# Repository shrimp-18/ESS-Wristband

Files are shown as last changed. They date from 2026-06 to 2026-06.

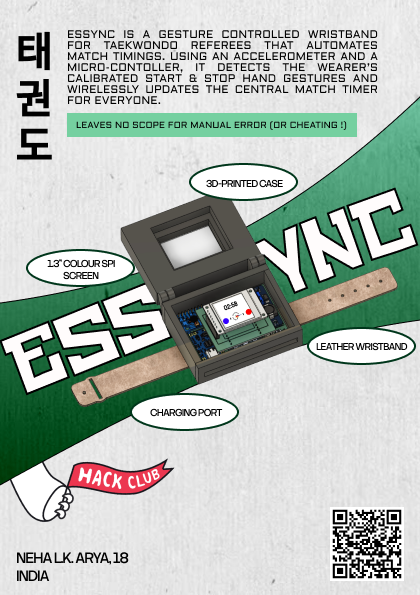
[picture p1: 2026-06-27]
Images/zine2.png

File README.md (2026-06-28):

# ESSync Wristband

A gesture-controlled referee wristband that automates match timing in Taekwondo. Using an accelerometer and microcontroller, it detects the referee’s calibrated start and stop gestures and wirelessly updates the central timer visible to everyone. This system removes manual jury control, ensuring accurate, fair, and transparent timekeeping.

---

## How it works

- Referee wants to stop the match.
- They make a swift hand movement used traditionally in Taekwondo.
- Players see this hand movement and stop.
- ESSync senses this swift hand movement and sends a signal to the central timer to stop.
- The central timer stops, and so do all the other sensors.
- Similar process repeats when the referee wants to restart the match.
zine3

<br>





---

## Why is ESSync Needed?

In Taekwondo matches, round timing is controlled by officials sitting at the jury table rather than by the referee overseeing the bout. This separation often leads to inconsistencies in the start and stop of the timer, whether due to human delay, miscommunication, or, in some cases, bias.
As a result, athletes can be unfairly advantaged or disadvantaged by inaccurate match durations, compromising the fairness and integrity of the competition.
There is a critical need for a referee-operated, automated, and transparent timing system that ensures real-time synchronisation and impartial timekeeping.

---

## So What's the solution?!

- A gesture-controlled wristband worn by referees to automate match timing.
- Uses an accelerometer and microcontroller to detect specific referee gestures.
- The downward "stop" motion of the hand instantly triggers the central arena timer wirelessly.
- Calibrated for each referee to prevent false detections and ensure precision.
- Removes jury dependency, ensuring fair, transparent, and real-time timekeeping.
- The timer part of Taekwondo matches isn’t automated yet and really needs a cheap and effective solution.
- Wristbands are easy to make and reliable.

---

## Components and their uses

| Component | Purpose |
|---|---|
| ESP32-C3 DevKitM-1 | Main MCU, the "brain" of the wristband |
| MPU6050 | Detects referee hand gestures |
| 1.3" 240×240 SPI Display | Displays timer and status |
| MT3608 | Boost converter |
| TP4056 | LiPo battery charger |

---


## Top PCB




---

## Bottom PCB





The project is made with two PCBs. The upper PCB holds the display, while the bottom PCB contains the MCU and all other components. This approach keeps the wristband compact without making it too wide. In future revisions, I plan to make it even smaller. The Case closes shut using the magnets present on the bottom part of the case and the lid of the case. The PCBs are snug in the case. The bottom PCB is also mounted to the bottom case by simply fitting the PCB's holes over the protruding cylindrical parts on the inner base of the case.

---

## Fusion Files

https://a360.co/4gCFWl9

---


## How to Build

## 1. Manufacture the PCBs
Fabricate both the **Top PCB** and **Bottom PCB** using the KiCad Files provided.

---

## 2. Prepare the Components

Purchase all required components listed in the **Bill of Materials (BOM)**.

---

## 3. Solder the Bottom PCB

Assemble the Bottom PCB first.
Solder All components and connectors to the bottom PCB according to the KiCad files given, and attach their respective components.

Refer to the schematic for the correct connector orientation and pin mapping.

---

## 4. Assemble the Top PCB

1. Solder the female headers for the ESP32 connector(on the bottom side).
2. Solder the male headers for the SPI Screen(on the top side).
3. Connect the SPI Screen.

---

## 5. Join the Two PCBs

Carefully align the connector pins and stack the 2 PCBs.

---

## 6. Upload the Firmware

1. Connect the ESP32-C3 to your computer using a USB cable.
2. Open the firmware in the Arduino IDE.
3. Select **ESP32-C3 Dev Module** as the target board.
4. Choose the correct serial port.
5. Compile and upload the firmware.

## 7. Assemble the Enclosure

3D-print the enclosure using the CAD files.

Install the assembled electronics inside the case.
No screws are required to mount as the pcb is snug in the case.
Glue Magnets to the base and lid of the case so that it can remain closed.

---

## 8. Attach a Wrist Strap

The wrist strap is **not** 3D printed </3
It's a DIY thing you need to do with a leather sheet.
Please add a strap to the bottom case through the space given underneath (I will be updating this with a better option in the future).

---

## 9. Power On

If assembled correctly, ESSync should be working! YAY!

---
## How to Use

You'll need to calibrate your hand gestures with the watch so it can record those values and stop/start the timer the next time you use it.

## Bill of Materials

| S.No. | Reference | Value | Product | Notes | Qty | Cost | Link |
|---:|---|---|---|---|----:|-----:|---|
| 1 | SPI_SCREEN1 | Conn_01x07 | Connector Pin Socket P2.54mm Vertical 1×7 | Top PCB (Display Connector) | 1 | $0.09 | https://robocraze.com/products/40x1-female-berg-strip |
| 2 | — | — | 1.3" 240×240 SPI Display | External Module | 1 | $9.50 | https://www.waveshare.com/1.3inch-lcd-module.htm |
| 3 | U3 | ESP32-C3-DevKitM-1 | ESP32-C3 DevKitM-1 | Bottom PCB | 1 | $10.11 | https://www.electropi.in/espressif-esp32-c3-devkitm-1-n4x-development-board |
| 4 | J1, J2 | Conn_01x15 | 1×15 Female Pin Socket | Bottom of Top PCB | 2 | $0.09 | https://robocraze.com/products/40x1-female-berg-strip |
| 5 | J7, J8, J9, J10 | Conn_01x01 | 1×01 Pin Header | MT3608 Connection | 4 | $0.06 | https://robocraze.com/products/40x1-pin-2-54mm-pitch-male-berg-strip |
| 6 | — | — | MT3608 Boost Module | External Module | 1 | $0.47 | https://www.flyrobo.in/mt3608-2a-dc-dc-boost-ultra-power-module |
| 7 | MPU6050 | Conn_01x08 | 1×08 Pin Header | MPU6050 Connector | 1 | $0.06 | https://robocraze.com/products/40x1-pin-2-54mm-pitch-male-berg-strip |
| 8 | — | — | MPU6050 Module | External Module | 1 | $1.63 | https://robocraze.com/products/mpu-6050-triple-axis-accelerometer-gyroscope-module |
| 9 | J5, J6, J11, J12 | Conn_01x01 | 1×01 Pin Header | TP4056 Connection | 4 | $0.06 | https://robocraze.com/products/40x1-pin-2-54mm-pitch-male-berg-strip |
| 10 | — | — | TP4056 Charging Module | External Module | 1 | $0.17 | https://quartzcomponents.com/products/tp4056-battery-charging-module |
| 11 | S1 | Tactile Button, 160gf | TS-1088-AR02016 | ESP ON Button | 1 | $0.06 | https://jlcpcb.com/partdetail/XUNPU-TS_1088AR02016/C720477 |
| 12 | SW1 | SW_Slide_DPDT | PCM12 Slide Switch | Power Switch | 1 | $1.20 | https://www.digikey.in/en/products/detail/c-k/PCM12SMTR/1640112 |
| 13 | Battery1 | Conn_01x02 | JST Battery Connector | Battery Connector | 1 | $0.05 | https://robu.in/product/b2b-xh-alfsn-jst-1x2p-2p-xh-tin-2-25%E2%84%8385%E2%84%83-3a-1-2-5mm-brass-direct-insert-pluginp2-5mm-wire-to-board-connector-rohs/ |
| 14 | — | — | 3.7V LiPo Battery | External Module | 1 | $1.69 | https://robocraze.com/products/450mah-3-7v-lipo-rechargeable-battery |
| 15 | C1 | 0.1µF | 0603 Capacitor | Decoupling Capacitor | 1 | $0.04 | https://robu.in/product/0603b104j500nt-fh-50v-100nf-x7r%C2%B15-0603-multilayer-ceramic-capacitors-mlcc-smd-smt-rohs/ |
| 16 | — | — | PCB Fabrication | Two Custom PCBs | 2 | $2.00 | https://cart.jlcpcb.com/quote |
| 17 | — | — | 3D Printed Case | External | 1 | $4.00 | https://zbotic.in/product/online-3d-printing-service |
| 18 | — | — | Leather Strap | External | 1 | $0.40 | https://www.desertcart.in/products/425174482-genuine-leather-strip-1-2-inch-wide-72-inches-long |
| 19 | — | — | Magnets | Externsl | 1 | $0.40 | https://www.prayogindia.in/product/neodymium-magnet-3mm-x-1mm-n35-super-strong-magnets/ |

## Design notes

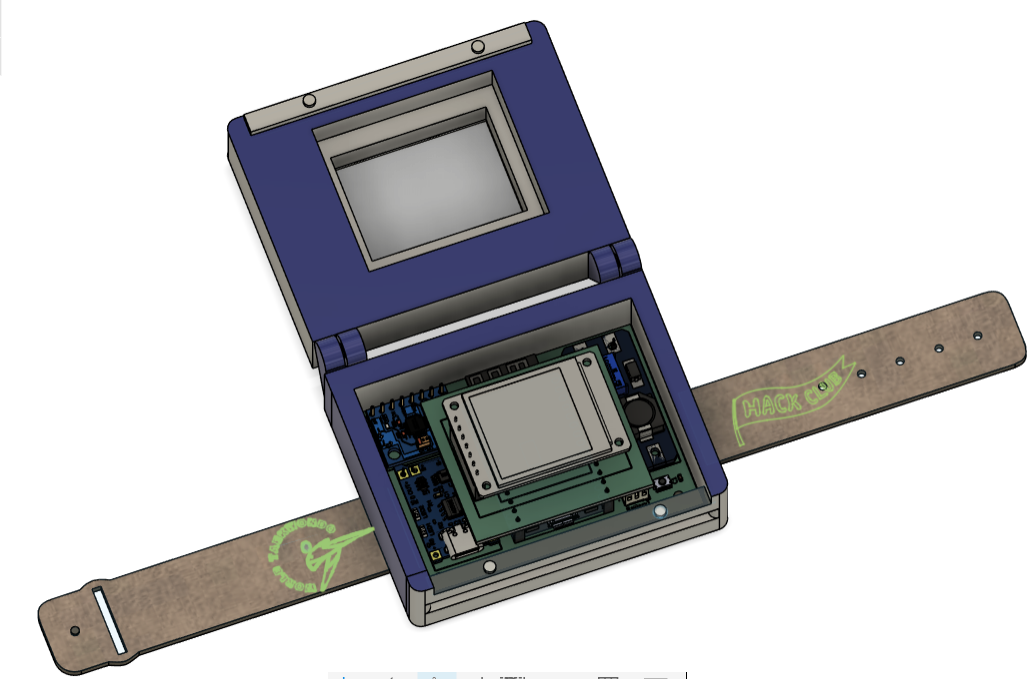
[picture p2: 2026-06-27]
Images/wristband_cad.png

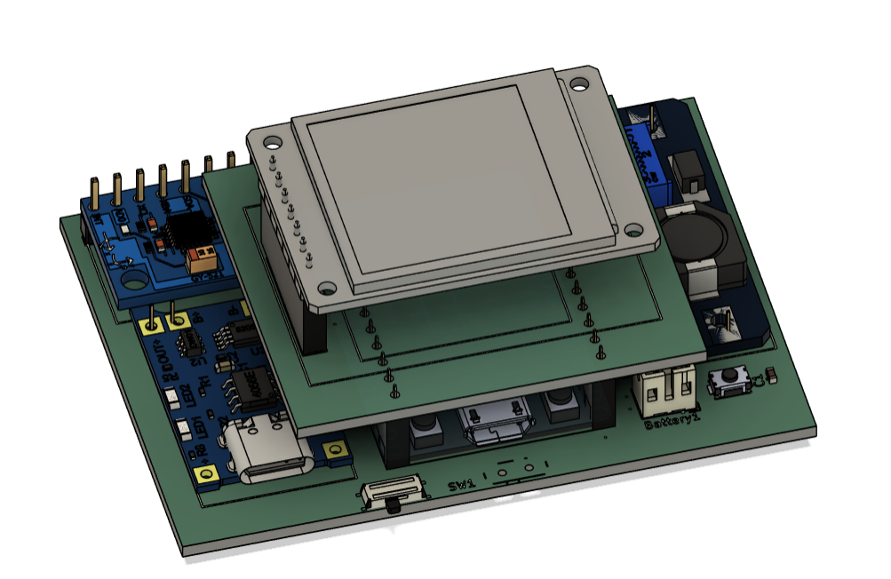
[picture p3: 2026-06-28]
Images/pcb.png

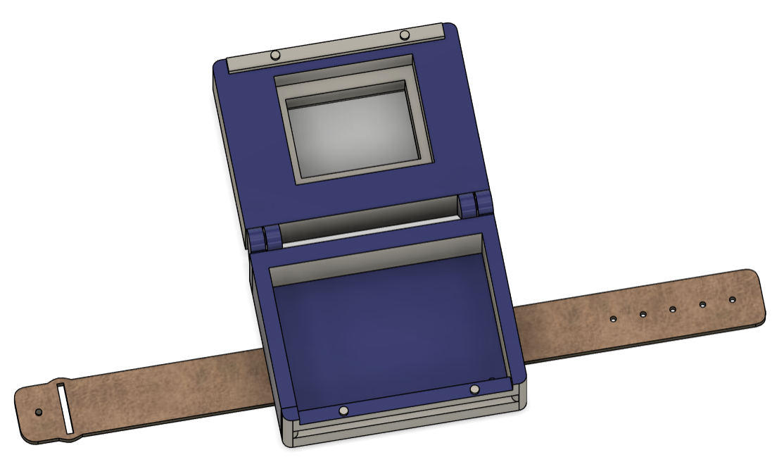
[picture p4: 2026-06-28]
Images/case.png

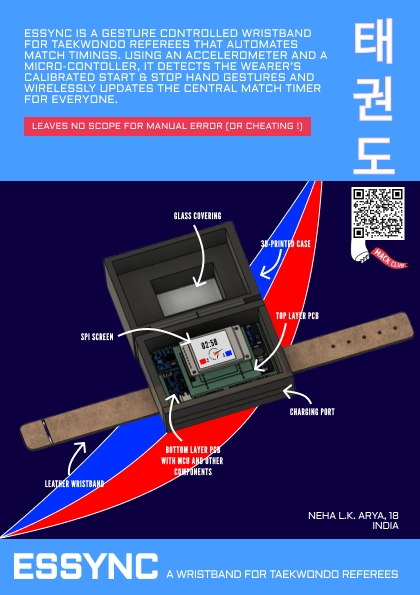
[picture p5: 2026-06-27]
Images/zinee.png

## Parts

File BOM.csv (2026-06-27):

S No. | Reference | Value | Product Name | Note | Quantity | Cost | Link
1 | SPI_SCREEN1 | Conn_01x07 | Connector PinSocket P2.54mm Vertical 1x7 | On Top PCB, for SPI Screen | 1 | 0.09US$ | https://robocraze.com/products/40x1-female-berg-strip
2 |  |  | 1.3 Inch 240X240 SPI SCREEN | Not on PCB, External | 1 | 9.5 US$ | https://www.waveshare.com/1.3inch-lcd-module.htm
3 | U3 | ESP32-C3-DevKitM-1 | ESP 32 C3 DEVKIT M1 | On Bottom PCB | 1 | 10.11US$ | https://www.electropi.in/espressif-esp32-c3-devkitm-1-n4x-development-board
4 | J1, J2 | Conn_01x15 | Connector PinSocket 1x15_P2.54mmVertical | On Lower side of Top PCB, for ESP | 2 | 0.09US$ | https://robocraze.com/products/40x1-female-berg-strip?_pos=3&_sid=d12dcc8d2&_ss=r
5 | J7,J8,J9,J10 | Conn_01x01 | Connector PinHeader1x01_P1mm_Vertical | On Bottom PCB, for MT3608 | 4 | 0.06US$ | https://robocraze.com/products/40x1-pin-2-54mm-pitch-male-berg-strip
6 |  |  | MT3608 | Not on PCB, External | 1 | 0.47US$ | https://www.flyrobo.in/mt3608-2a-dc-dc-boost-ultra-power-module
7 | MPU6050 | Conn_01x08 | Connector PinHeader1x08_P2.54mmVertical | On Bottom PCB, for MPU6050 | 1 | 0.06US$ | https://robocraze.com/products/40x1-pin-2-54mm-pitch-male-berg-strip
8 |  |  | MPU6050 | Not on PCB, External | 1 | 1.63US$ | https://robocraze.com/products/mpu-6050-triple-axis-accelerometer-gyroscope-module
9 | J5,J6,J11,J12 | Conn_01x01 | Connector PinHeader1x01_P1mm Vertical | On Bottom PCB, for TP4056 | 4 | 0.06US$ | https://robocraze.com/products/40x1-pin-2-54mm-pitch-male-berg-strip
10 |  |  | TP4056 | Not on PCB, External | 1 | 0.17US$ | https://quartzcomponents.com/products/tp4056-battery-charging-module
11 | S1 | Tactile Button, 160gf | PCM_JLCPCB:SW_TS-1088-AR02016 | On Bottom PCB, ESP ON Switch | 1 | 0.06US$ | https://jlcpcb.com/partdetail/XUNPU-TS_1088AR02016/C720477
12 | SW1 | SW_Slide_DPDT | Button_Switch_SMD:SW_SPDT_PCM12 | On Bottom PCB, Power ON/OFF | 1 | 1.2US$ | https://www.digikey.in/en/products/detail/c-k/PCM12SMTR/1640112
13 | Battery1 | Conn_01x02 | Connector_JST:JST_PH_B2B-PH-K_1x02_P2.00mm_Vertical | On Bottom PCB, for Battery | 1 | 0.05US$ | https://robu.in/product/b2b-xh-alfsn-jst-1x2p-2p-xh-tin-2-25%E2%84%8385%E2%84%83-3a-1-2-5mm-brass-direct-insert-pluginp2-5mm-wire-to-board-connector-rohs/
14 |  |  | Battery | Not on PCB, External | 1 | 1.69US$ | https://robocraze.com/products/450mah-3-7v-lipo-rechargeable-battery
15 | C1 | 0.1uF | Capacitor_SMD:C_0603_1608Metric | On Bottom PCB, Decoupling Capacitor | 1 | 0.04US$ | https://robu.in/product/0603b104j500nt-fh-50v-100nf-x7r%C2%B15-0603-multilayer-ceramic-capacitors-mlcc-smd-smt-rohs/
16 |  |  | PCBs |  | 2 | 2US$ | https://cart.jlcpcb.com/quote
17 |  |  | 3D-Printing Case |  | 1 | 4US$ | https://zbotic.in/product/online-3d-printing-service
18 |  |  | Leather Strap |  | 1 | 0.4$ | https://www.desertcart.in/products/425174482-genuine-leather-strip-1-2-inch-wide-72-inches-long
19 |  |  | Magnets |  | 4 | 0.4$ | https://www.prayogindia.in/product/neodymium-magnet-3mm-x-1mm-n35-super-strong-magnets/
 |  |  | Total: |  | 26 | 32.08 US$

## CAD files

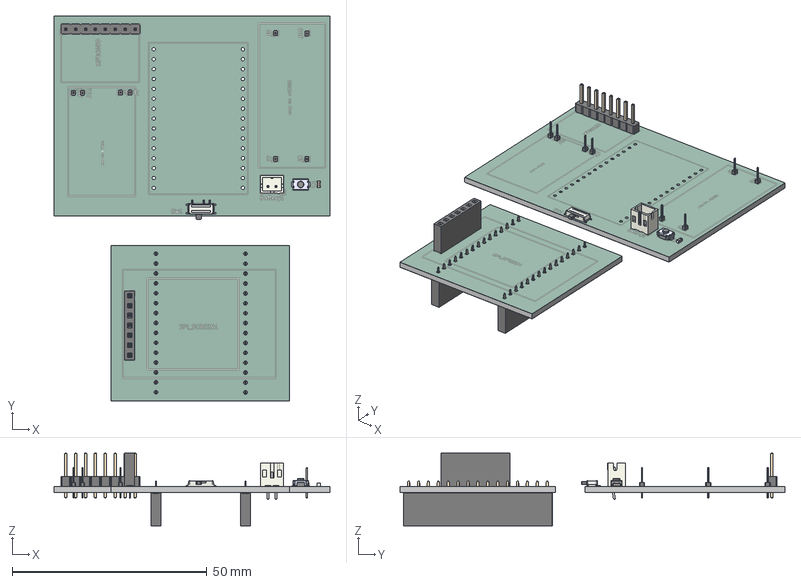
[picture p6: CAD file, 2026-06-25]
src/cad/ESSync.step
70.8 x 98.8 x 18.7 mm
PinHeader_1x01_P1.00mm_Vertical x 8
PinSocket_1x07_P2.54mm_Vertical
TS-1088-AR02016
PinHeader_1x08_P2.54mm_Vertical
SW_SPDT_PCM12
C_0603_1608Metric
JST_PH_B2B-PH-K_1x02_P2.00mm_Vertical
PinSocket_1x15_P2.54mm_Vertical x 2
ESSync_silkscreen x 2
ESSync_soldermask x 2
ESSync_PCB_1
ESSync_PCB_2

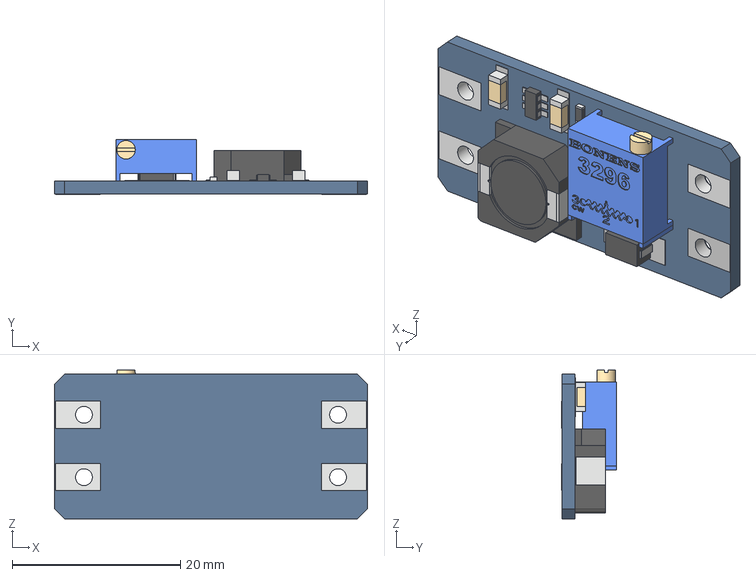
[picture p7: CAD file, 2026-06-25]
src/cad/models/MT3608 v3.step
37.2 x 6.49 x 17.7 mm

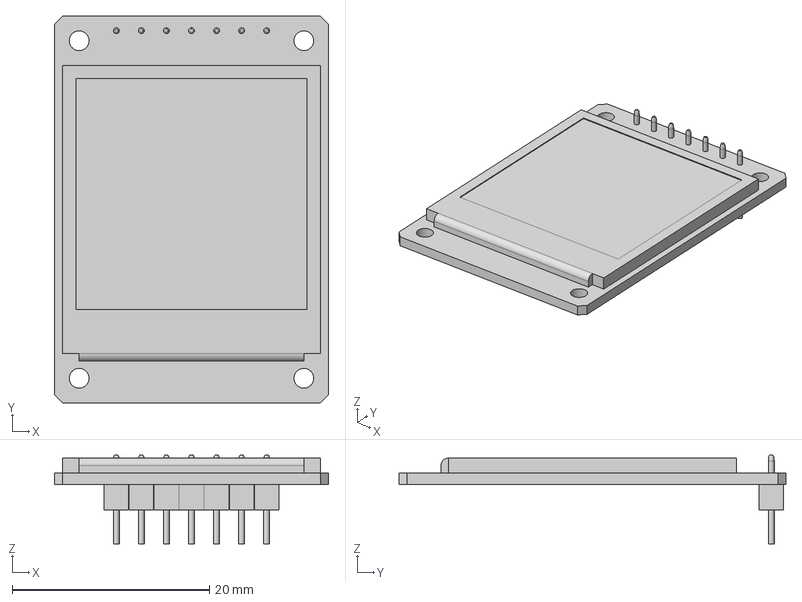
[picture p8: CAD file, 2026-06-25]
src/cad/models/IPS 240 x 240 1.3 Inch.step
27.8 x 39.2 x 9.00 mm

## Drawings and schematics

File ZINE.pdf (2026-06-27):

태
권

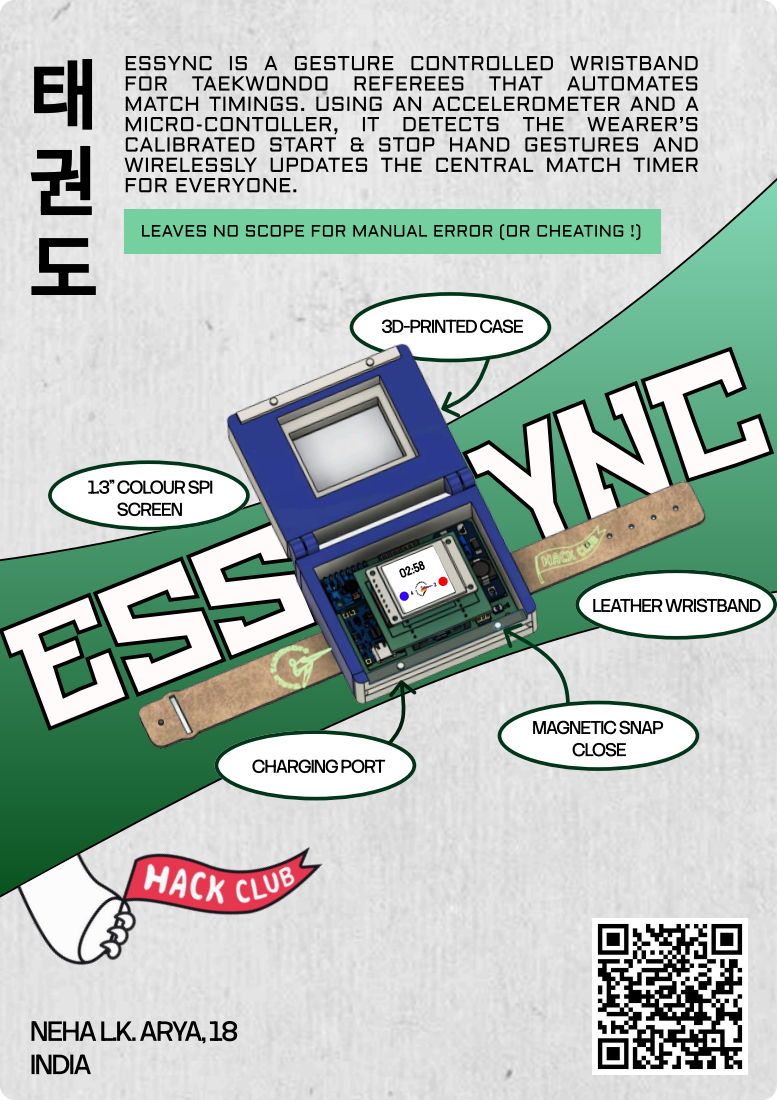
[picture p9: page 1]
FOR; TAEKWONDO; REFEREES; THAT; AUTOMATES; MICRO-CONTOLLER,; DETECTS; THE; WEARER’S CALIBRATED START & STOP HAND GESTURES AND; 3D-PRINTED CASE; 1.3’’ COLOUR SPI; SCREEN; LEATHER WRISTBAND; MAGNETIC SNAP; NEHA L.K. ARYA, 18; INDIA

ESSYNC IS A GESTURE CONTROLLED WRISTBAND
MATCH TIMINGS. USING AN ACCELEROMETER AND A

WIRELESSLY UPDATES THE CENTRAL MATCH TIMER
FOR EVERYONE.

LEAVES NO SCOPE FOR MANUAL ERROR (OR CHEATING !)

CLOSE CHARGING PORT

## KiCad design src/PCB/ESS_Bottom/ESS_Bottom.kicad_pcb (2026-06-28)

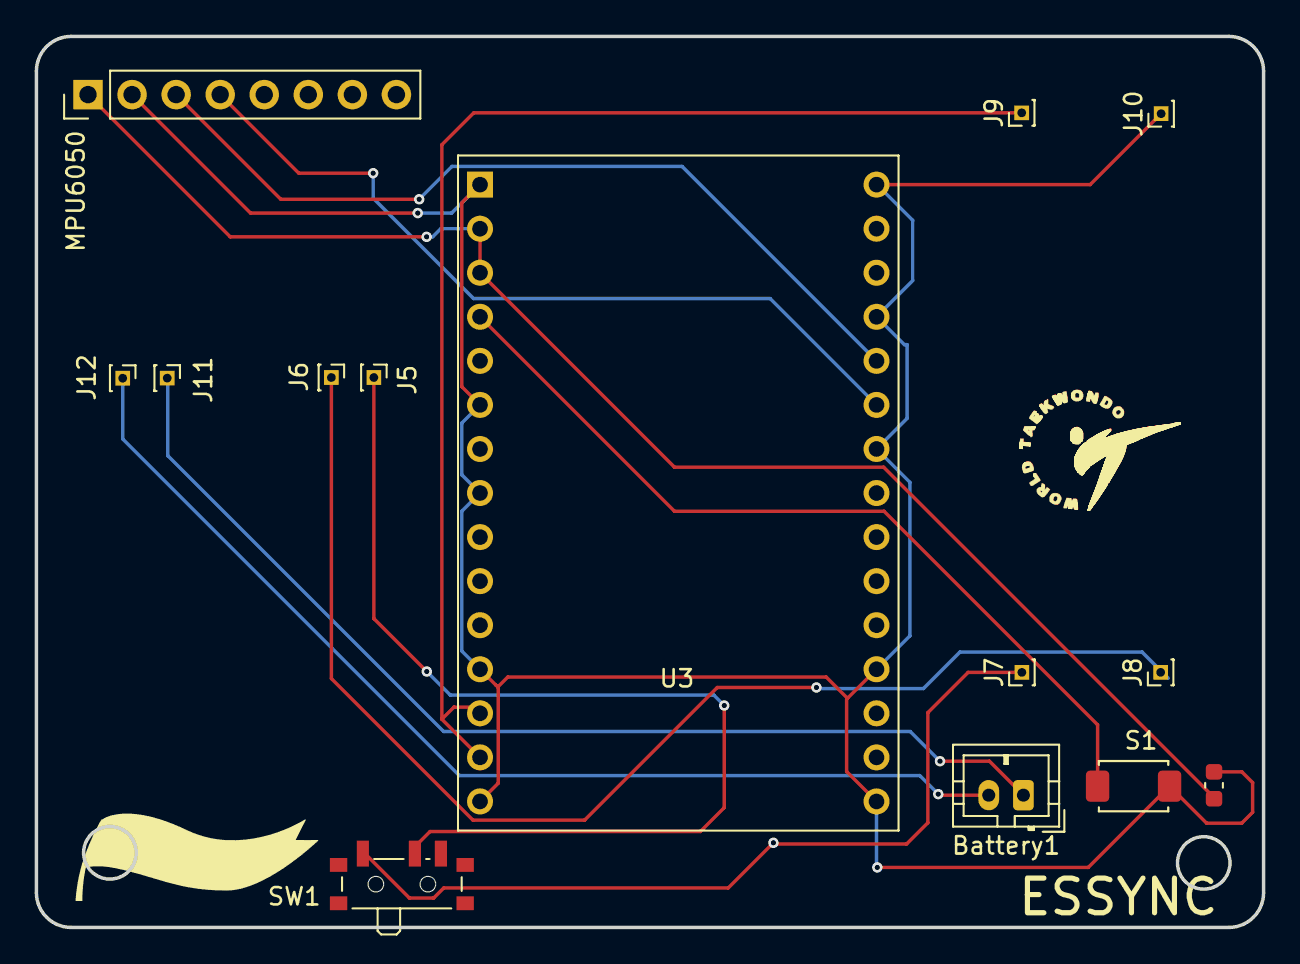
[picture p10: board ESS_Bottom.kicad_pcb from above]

Board: 2 copper layers, 70.8 x 51.4 mm, 14 parts (0 on the bottom side), 11 nets.

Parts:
Battery1: Conn_01x02; JST_PH_B2B-PH-K_1x02_P2.00mm_Vertical
C1: 0.1uF; C_0603_1608Metric
J5, J6, J7, J8, J9, J10, J11, J12: Conn_01x01; PinHeader_1x01_P1.00mm_Vertical
MPU6050: Conn_01x08; PinHeader_1x08_P2.54mm_Vertical
S1: Tactile Button, 160gf; SW_TS-1088-AR02016
SW1: SW_Slide_DPDT; SW_SPDT_PCM12
U3: ESP32-C3-DevKitM-1

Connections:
+3.3V: C1.1, MPU6050.1, U3.2 (3V3), U3.3 (3V3)
+5V: J9.1, U3.13 (5V), U3.14 (5V)
/BAT+: Battery1.1, J11.1
/BAT-: Battery1.2, J12.1
/GPIO2: S1.1 (A), U3.4 (IO2)
/IN+: J7.1, SW1.1 (A)
/IN-: J6.1, J8.1
/OUT+: J5.1, SW1.2 (B)
/SCL: MPU6050.3, U3.26 (IO9)
/SDA: MPU6050.4, U3.25 (IO8)
GND: C1.2, J10.1, MPU6050.2, S1.2 (B), U3.1 (GND), U3.6 (GND), U3.8 (GND), U3.12 (GND), U3.15 (GND), U3.16 (GND), U3.19 (GND), U3.24 (GND), U3.27 (GND), U3.30 (GND)

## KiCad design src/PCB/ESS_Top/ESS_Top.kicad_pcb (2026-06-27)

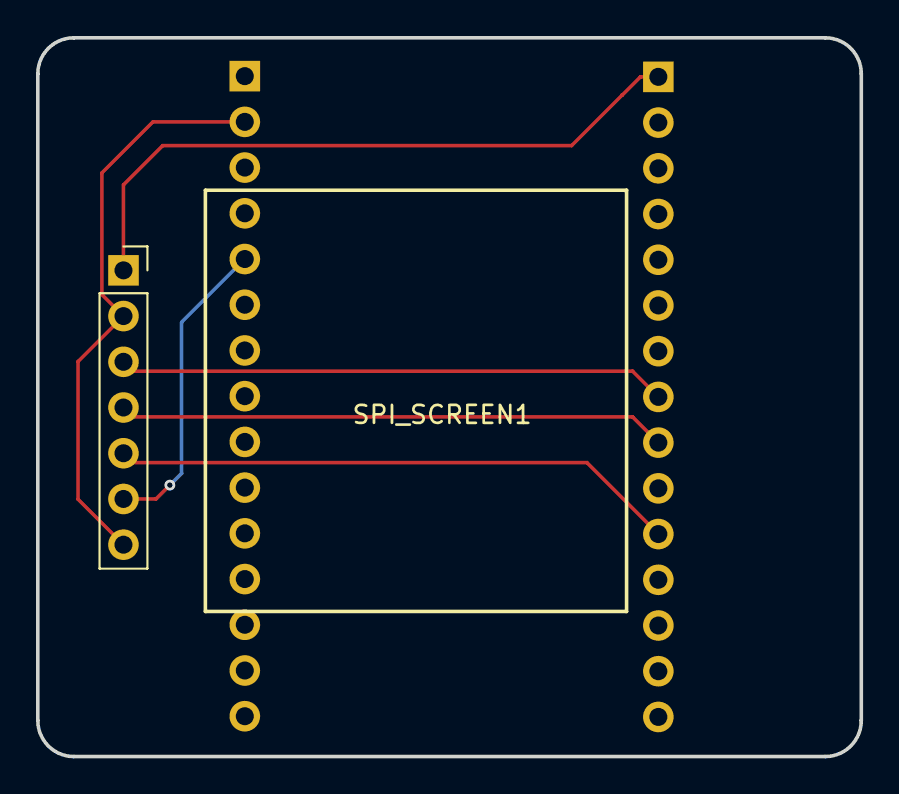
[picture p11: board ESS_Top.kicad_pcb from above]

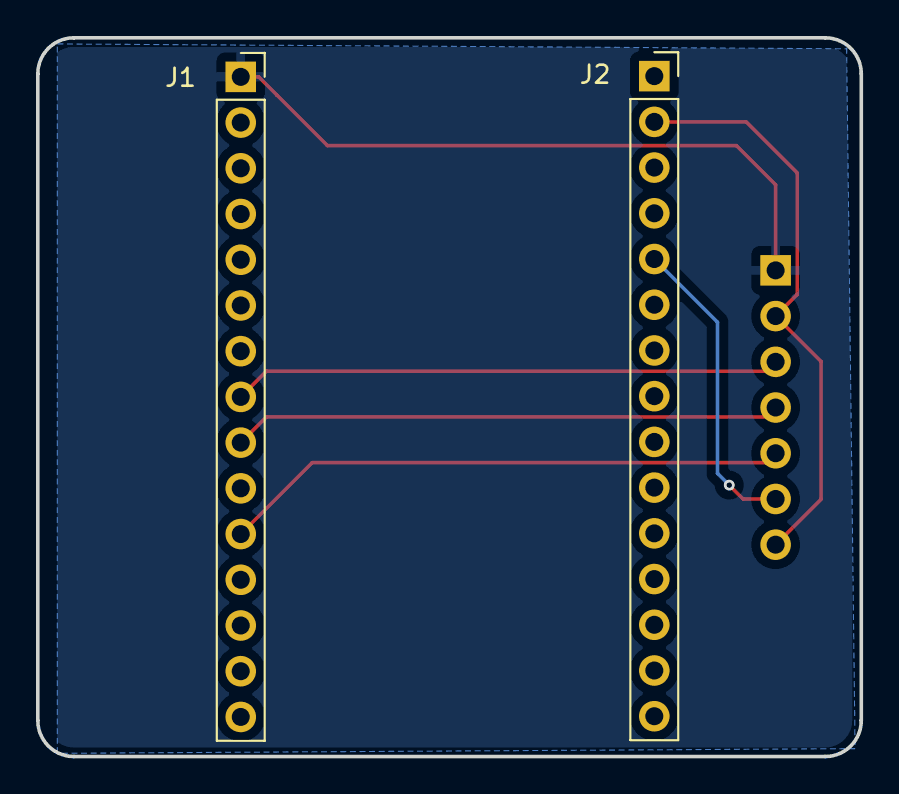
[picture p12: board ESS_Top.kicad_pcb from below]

Board: 2 copper layers, 45.7 x 39.9 mm, 3 parts (2 on the bottom side), 6 nets.

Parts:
J1, J2: Conn_01x15; PinSocket_1x15_P2.54mm_Vertical
SPI_SCREEN1: Conn_01x07; PinSocket_1x07_P2.54mm_Vertical

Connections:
+3.3V: J2.2 (3V3), SPI_SCREEN1.2, SPI_SCREEN1.7
/DC: J2.5 (GPIO3), SPI_SCREEN1.6
/RES: J1.11 (GPIO4), SPI_SCREEN1.5
/SCL_SPI: J1.8 (GPIO7), SPI_SCREEN1.3
/SDA_SPI: J1.9 (GPIO6), SPI_SCREEN1.4
GND: J1.1 (GND), SPI_SCREEN1.1

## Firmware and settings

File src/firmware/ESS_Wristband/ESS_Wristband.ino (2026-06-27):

#include <Wire.h>
#include <SPI.h>
#include <Adafruit_GFX.h>
#include <Adafruit_ST7789.h>
#include <Adafruit_MPU6050.h>
#include <Adafruit_Sensor.h>
#define TFT_CS    -1
#define TFT_DC     3
#define TFT_RST    4
#define TFT_MOSI   6
#define TFT_SCLK   7
#define MPU_SDA    8
#define MPU_SCL    9
#define BUTTON_PIN 2

Adafruit_ST7789 tft =
Adafruit_ST7789(
    TFT_CS,
    TFT_DC,
    TFT_RST
);

Adafruit_MPU6050 mpu;

enum MatchState
{
    READY,
    RUNNING,
    PAUSED
};

MatchState state = READY;

const uint16_t MATCH_TIME = 180;
uint16_t remainingTime = MATCH_TIME;
unsigned long lastSecond = 0;
bool timerRunning = false;

float ax = 0;
float ay = 0;
float az = 0;
float gx = 0;
float gy = 0;
float gz = 0;

uint8_t batteryPercent = 100;
bool lastButton = HIGH;
unsigned long lastDebounce = 0;

void drawSplash()
{

    tft.fillScreen(ST77XX_BLACK);
    tft.setTextColor(ST77XX_WHITE);
    tft.setTextSize(3);
    tft.setCursor(70,30);
    tft.println("ESS");
    tft.setTextSize(2);
    tft.setCursor(18,90);
    tft.println("Electronic");
    tft.setCursor(42,118);
    tft.println("Scoring");
    tft.setCursor(50,146);
    tft.println("System");
    tft.drawLine(
        20,
        180,
        220,
        180,
        ST77XX_BLUE
    );

    tft.setCursor(28,195);
    tft.setTextColor(ST77XX_CYAN);
    tft.println("Initializing...");
}

void drawHome()
{
    tft.fillScreen(ST77XX_BLACK);
    tft.setTextSize(2);
    tft.setTextColor(ST77XX_WHITE);
    tft.setCursor(55,10);
    tft.print("ROUND 1");

    drawTimer();
    drawStatus();
    drawBattery();

}
void drawTimer()
{

    char buf[10];

    sprintf(
        buf,
        "%02d:%02d",
        remainingTime/60,
        remainingTime%60
    );

    tft.fillRect(
        20,
        55,
        200,
        70,
        ST77XX_BLACK
    );

    tft.setTextColor(ST77XX_WHITE);
    tft.setTextSize(5);

    tft.setCursor(
        25,
        65
    );

    tft.print(buf);

}
void drawStatus()
{

    tft.fillRect(
        0,
        145,
        240,
        30,
        ST77XX_BLACK
    );

    tft.setTextSize(2);

    switch(state)
    {

        case READY:
        tft.setTextColor(ST77XX_BLUE);
        tft.setCursor(72,150);
        tft.print("READY");
        break;
        
        case RUNNING:
        tft.setTextColor(ST77XX_GREEN);
        tft.setCursor(55,150);
        tft.print("RUNNING");
        break;

        case PAUSED:
        tft.setTextColor(ST77XX_YELLOW);
        tft.setCursor(60,150);
        tft.print("PAUSED");
        break;

    }

}
void drawBattery()
{

    tft.fillRect(
        15,
        205,
        210,
        25,
        ST77XX_BLACK
    );

    tft.setTextSize(1);
    tft.setTextColor(ST77XX_CYAN);
    tft.setCursor(15,210);
    tft.print("Battery ");
    tft.print(batteryPercent);
    tft.print("%");
    tft.drawRect(
        170,
        208,
        42,
        12,
        ST77XX_WHITE
    );

    int width =
    map(
        batteryPercent,
        0,
        100,
        0,
        40
    );

    tft.fillRect(
        171,
        209,
        width,
        10,
        ST77XX_GREEN
    );

}
void updateTimer()
{
    if (!timerRunning)
        return;

    if (millis() - lastSecond >= 1000)
    {
        lastSecond = millis();

        if (remainingTime > 0)
        {
            remainingTime--;
            drawTimer();
        }
        else
        {
            timerRunning = false;
            state = READY;

            drawStatus();
        }
    }
}

void checkButton()
{
    bool currentButton = digitalRead(BUTTON_PIN);

    if (currentButton != lastButton)
    {
        lastDebounce = millis();
    }

    if (millis() - lastDebounce > 50)
    {
        if (lastButton == HIGH && currentButton == LOW)
        {
            switch (state)
            {
                case READY:

                    state = RUNNING;
                    timerRunning = true;

                    break;

                case RUNNING:

                    state = PAUSED;
                    timerRunning = false;

                    break;

                case PAUSED:

                    state = RUNNING;
                    timerRunning = true;

                    break;
            }

            drawStatus();
        }
    }

    lastButton = currentButton;
}

void readMPU()
{
    sensors_event_t accel;
    sensors_event_t gyro;
    sensors_event_t temp;

    mpu.getEvent(
        &accel,
        &gyro,
        &temp
    );

    ax = accel.acceleration.x;
    ay = accel.acceleration.y;
    az = accel.acceleration.z;

    gx = gyro.gyro.x;
    gy = gyro.gyro.y;
    gz = gyro.gyro.z;

    Serial.print("AX: ");
    Serial.print(ax);

    Serial.print(" AY: ");
    Serial.print(ay);

    Serial.print(" AZ: ");
    Serial.print(az);

    Serial.print(" | GX: ");
    Serial.print(gx);

    Serial.print(" GY: ");
    Serial.print(gy);

    Serial.print(" GZ: ");
    Serial.println(gz);
}


void updateBattery()
{
    static unsigned long previous = 0;

    if (millis() - previous < 5000)
        return;

    previous = millis();

    if (batteryPercent > 20)
        batteryPercent--;

    drawBattery();
}


void drawIMUDebug()
{
    tft.fillRect(
        0,
        175,
        240,
        25,
        ST77XX_BLACK
    );
    tft.setTextSize(1);
    tft.setTextColor(ST77XX_WHITE);
    tft.setCursor(5,180);
    tft.print("AZ:");
    tft.print(az,1);
    tft.print(" GX:");
    tft.print(gx,1);
}
void setup()
{
    Serial.begin(115200);
    Serial.println();
    Serial.println("*********************************");
    Serial.println(" ESSync Wristband");
    Serial.println(" Firmware 1");
    Serial.println("*********************************");
    pinMode(BUTTON_PIN, INPUT_PULLUP);

    SPI.begin(
        TFT_SCLK,
        -1,
        TFT_MOSI
    );

    tft.init(240,240);
    tft.setRotation(0);
    drawSplash();
    delay(2000);

    Wire.begin(
        MPU_SDA,
        MPU_SCL
    );
    
    if(!mpu.begin())
    {
        tft.fillScreen(ST77XX_RED);
        tft.setTextColor(ST77XX_WHITE);
        tft.setTextSize(2);
        tft.setCursor(15,110);
        tft.println("MPU6050 NOT FOUND");
        Serial.println("MPU6050 FAILED");
        while(true);
    }

    Serial.println("MPU6050 OK");
    drawHome();
    lastSecond = millis();
}


void loop()
{
    readMPU();
    checkButton();
    updateTimer();
    updateBattery();
    drawIMUDebug();
    delay(10);
}

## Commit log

2026-05-13 Added all ESSync files from KiCad
    [ESSync.kicad_pcb, ESSync.kicad_sch, ESSync.step]
2026-05-13 3d models of components used in this project
    [IPS 240 x 240 1.3 Inch.step, MT3608 v3.step]
2026-06-25 Added updated files of pcb
    [ESSync.kicad_pcb, ESSync.kicad_sch, ESSync.step]
2026-06-25 Organized files
    [BOM.csv, ESSync.kicad_pcb, ESSync.kicad_sch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]
2026-06-27 added firmware files
    [ESS_Bottom.kicad_pcb, ESS_Bottom.kicad_sch, ESS_Top.kicad_pcb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]
2026-06-27 made kicad files cleaner?
    [ESS_Bottom.kicad_sch, ESS_Top.kicad_sch]
2026-06-27 added final cad file
2026-06-27 oooo hmmmm
    [ESS_Bottom.kicad_sch]
2026-06-27 fab layer
    [ESS_Bottom.kicad_pcb, ESS_Top.kicad_pcb]
2026-06-27 made src folder bcs alice told
    [ESS_Bottom.kicad_pcb, ESS_Bottom.kicad_sch, ESS_Top.kicad_pcb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]
2026-06-27 file names
    [ESSync.step, IPS 240 x 240 1.3 Inch.step, MT3608 v3.step]
2026-06-27 added ground fill
    [BOM.csv, ESS_Bottom.kicad_pcb, ESS_Top.kicad_pcb]
2026-06-27 deleted gitignore files
    [BOM.csv]
2026-06-28 made holes in pcb for mounting
    [ESS_Bottom.kicad_pcb]
